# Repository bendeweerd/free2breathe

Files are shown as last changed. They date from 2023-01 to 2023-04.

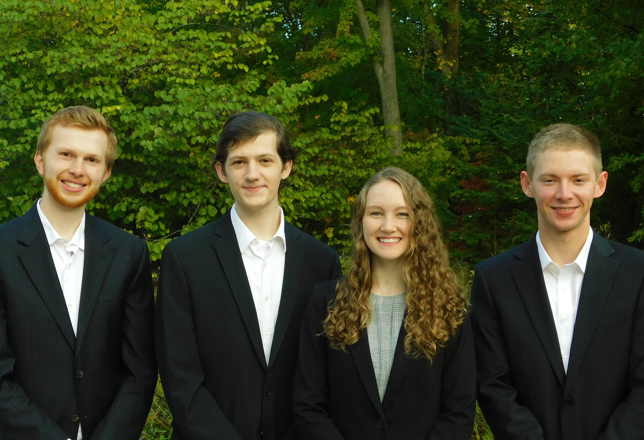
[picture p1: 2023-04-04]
website_resources/team.jpg

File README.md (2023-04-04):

# free<sub>2</sub>breathe
Calvin University Senior Design Team 17, 2022-2023.

Free<sub>2</sub>breathe is a hazardous gas detector built using [SPEC sensors](https://www.spec-sensors.com/) and a custom PCB. It detects short-term and long-term hazardous levels of
1. Carbon Monoxide
2. Ozone
3. Sulfur Dioxide
4. Nitrogen Dioxide

and alerts the user if any of these gases are present in concentrations that will cause long-term or short-term harm.

Visit our [webpage](https://bendeweerd.github.io/free2breathe/index.html) to download the instructional pamphlet.

Team Members: 
1. Nate Anderson
2. Jordan Alexander
3. Ben DeWeerd
4. Anna Giboney

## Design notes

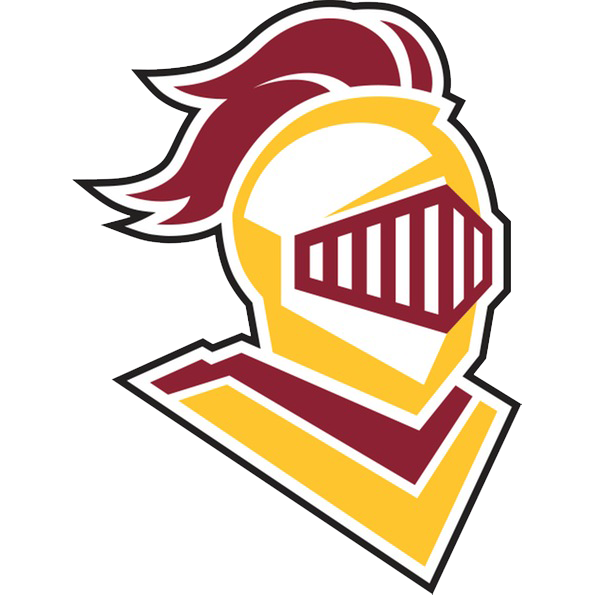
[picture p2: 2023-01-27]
free2breathe_pcb/knights.bmp

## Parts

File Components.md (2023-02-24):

# Components:

1. 1x Micro - Arduino Nano (Ben has)
2. 1x [ip5328](https://www.digipart.com/part/IP5328P)
3. 1x [Buzzer](https://www.digikey.com/en/products/detail/pui-audio-inc/AT-1127-ST-2-R/5011397)
4. 4x [MCP6044 Opamp](https://www.digikey.com/en/products/detail/microchip-technology/MCP6044-E-P/1098540)
5. 1x [Inductor](https://www.digikey.com/en/products/detail/abracon-llc/AMPLA5030S-2R2MT/12168435)
6. 1x [Thermistor](https://www.digikey.com/en/products/detail/mitsubishi-materials-u-s-a-corporation/TH20-3S104FT/12144110)
7. 1x [USB-C Connector](https://www.digikey.com/en/products/detail/gct/USB4110-GF-A/10384547)
8. 1x [Switch](https://www.digikey.com/en/products/detail/e-switch/EG1213/101735)
9. 1x [JST connector for LEDs](https://www.digikey.com/en/products/detail/jst-sales-america-inc/S3B-PH-K-S-LF-SN/926627)
10. 4x [Status LEDs](https://www.digikey.com/en/products/detail/inolux/INL-3AB30/7604618)
11. 4x [Charge LEDs (unless changed)](https://www.digikey.com/en/products/detail/qt-brightek-qtb/QBLP601-IW/4814655)
12. 1x [Q2 Transistor](https://www.digikey.com/en/products/detail/diodes-incorporated/DMN3404L-7/2052774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)
13. 1x [Q1 Transistor](https://www.digikey.com/en/products/detail/alpha-omega-semiconductor-inc/AO3401A/1855773)
14. 1x [10mOhm Resistor](https://www.digikey.com/en/products/detail/koa-speer-electronics-inc/UR73D2ATTD10L0F/9845679)

## REV 2:
1. 2x [15 Position headers for Nano](https://www.digikey.com/en/products/detail/sullins-connector-solutions/PPTC151LFBN-RC/810153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)
2. 12x [2 position headers for SPEC sensors](https://www.digikey.com/en/products/detail/adam-tech/2RS1-02-G/9833032)
3. 20x [Football Capacitors](https://www.digikey.com/en/products/detail/rubycon/50YXJ100MT78X11-5/3134938)
4. 1x [Thermistor](https://www.digikey.com/en/products/detail/mitsubishi-materials-u-s-a-corporation/TH20-3S104FT/12144110)

## To Purchase:
1. 4x [15 Position headers for Nano](https://www.digikey.com/en/products/detail/sullins-connector-solutions/PPTC151LFBN-RC/810153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)
2. 12x [2 position headers for SPEC sensors](https://www.digikey.com/en/products/detail/adam-tech/2RS1-02-G/9833032)
3. 30x [100nF 25V Capactiors](https://www.digikey.com/en/products/detail/samsung-electro-mechanics/CL10B104KA8NNNC/3886664)
4. 10x [1uF 25V Capacitors](https://www.digikey.com/en/products/detail/samsung-electro-mechanics/CL10A105KA8NNNC/3886760)
5. 2x [USB-C Connectors](https://www.digikey.com/en/products/detail/gct/USB4110-GF-A/10384547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)
6. 2x [2 kOhm Resistors](https://www.digikey.com/en/products/detail/susumu/RR0816P-202-D/432192)
7. 30x [1 MOhm Resistors](https://www.digikey.com/en/products/detail/yageo/RC0603JR-071ML/726678)
8. 4x [16.2 kOhm Resistors](https://www.digikey.com/en/products/detail/yageo/RC0603FR-0716K2L/726967)
9. 20x [100 kOhm Resistors](https://www.digikey.com/en/products/detail/yageo/RC0603FR-07100KL/726889)
10. 10x [49.9 Ohm Resistors](https://www.digikey.com/en/products/detail/yageo/RC0603FR-1349R9L/13694149)
11. 4x [499 kOhm Resistors](https://www.digikey.com/en/products/detail/yageo/RC0603FR-07499KL/727267)
12. 2x [143 kOhm Resistors](https://www.digikey.com/en/products/detail/yageo/RC0603FR-07143KL/726949)
13. 2x [Switch](https://www.digikey.com/en/products/detail/e-switch/EG1213/101735)
14. 2x [Thermistor](https://www.digikey.com/en/products/detail/mitsubishi-materials-u-s-a-corporation/TH20-3S104FT/12144110)

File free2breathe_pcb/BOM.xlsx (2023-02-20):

Source: | /home/bendeweerd/Documents/senior_design/free2breathe/free2breathe_pcb/free2breathe_pcb.kicad_sch
Date: | Thu 26 Jan 2023 10:10:45 AM EST
Tool: | Eeschema 6.0.9-8da3e8f707~116~ubuntu20.04.1
Generator: | /usr/share/kicad/plugins/bom_csv_grouped_by_value_with_fp.py
Component Count: | 101
Ref | Qnty | Value | Purchase Location | Link | Cmp name | Footprint | Description | Vendor
A1, | 1 | Arduino_Nano_v3.x | N/A |  | Arduino_Nano_v3.x | Module:Arduino_Nano | Arduino Nano v3.x
BT1, BT2, BT3, | 3 | Battery_Cell | N/A |  | Battery_Cell | switch:switch_pad | Single-cell battery
C1, C11, C13, | 3 | 10uF 25V | DigiKey | https://www.digikey.com/en/products/detail/samsung-electro-mechanics/CL10A106MA8NRNC/3887527 | C | Capacitor_SMD:C_0603_1608Metric | Unpolarized capacitor
C2, C7, C8, C9, C10, | 5 | 22uF 25V | DigiKey | https://www.digikey.com/en/products/detail/samsung-electro-mechanics/CL21A226MAYNNNE/10479857 | C | 0805 | Unpolarized capacitor
C3, C6, C12, | 3 | 100nF 25V | DigiKey | https://www.digikey.com/en/products/detail/samsung-electro-mechanics/CL10B104KA8NNNC/3886664 | C | Capacitor_SMD:C_0603_1608Metric | Unpolarized capacitor
C4, C5, | 2 | 2.2uF 16V | DigiKey | https://www.digikey.com/en/products/detail/samsung-electro-mechanics/CL10A225KO8NNNC/3886698 | C | Capacitor_SMD:C_0603_1608Metric | Unpolarized capacitor
C14, C16, C17, | 3 | 22uF 16V | DigiKey | https://www.digikey.com/en/products/detail/samsung-electro-mechanics/CL10A226MO7JZNC/7320581 | C | Capacitor_SMD:C_0603_1608Metric | Unpolarized capacitor
C15, | 1 | 22uF 16v |  |  | C | Capacitor_SMD:C_0603_1608Metric | Unpolarized capacitor
C18, C19, C20, C21, C22, C23, C24, C25, C26, C27, C28, C29, C30, C31, C32, | 15 | 0.1u | DigiKey | https://www.digikey.com/en/products/detail/samsung-electro-mechanics/CL10B104KO8NNNC/3886663 | C | Capacitor_SMD:C_0603_1608Metric | Unpolarized capacitor
D1, | 1 | Status_LED_1 | DigiKey | https://www.digikey.com/en/products/detail/inolux/INL-3AB30/7604618 | LED | LED_THT:LED_D3.0mm | Light emitting diode
D2, | 1 | Status_LED_2 |  |  | LED | LED_THT:LED_D3.0mm | Light emitting diode
D3, | 1 | Status_LED_3 |  |  | LED | LED_THT:LED_D3.0mm | Light emitting diode
D4, | 1 | Status_LED_4 |  |  | LED | LED_THT:LED_D3.0mm | Light emitting diode
D5, D6, D7, D8, | 4 | LED | DigiKey | https://www.digikey.com/en/products/detail/qt-brightek-qtb/QBLP601-IW/4814655 | LED | LED_SMD:LED_0603_1608Metric | Light emitting diode
H1, H2, H3, H4, H5, | 5 | MountingHole_Pad | N/A |  | MountingHole_Pad | MountingHole:MountingHole_3.2mm_M3_Pad_Via | Mounting Hole with connection
J1, | 1 | USB4110-GF-A_REVB | DigiKey | https://www.digikey.com/en/products/detail/gct/USB4110-GF-A/10384547 | USB4110-GF-A_REVB | components:GCT_USB4110-GF-A_REVB
J2, | 1 | LED_Connector | DigiKey | https://www.digikey.com/en/products/detail/jst-sales-america-inc/S3B-PH-K-S-LF-SN/926627 | Conn_01x03_Female | Connector_JST:JST_PH_S3B-PH-K_1x03_P2.00mm_Horizontal | Generic connector, single row, 01x03, script generated (kicad-library-utils/schlib/autogen/connector/)
J3, | 1 | Alarm_Connector | N/A |  | Conn_01x02_Female | alarm:AT_1127_ST_2_R_Alarm | Generic connector, single row, 01x02, script generated (kicad-library-utils/schlib/autogen/connector/)
L1, | 1 | 2.2uH | DigiKey | https://www.digikey.com/en/products/detail/abracon-llc/AMPLA5030S-2R2MT/12168435 | L | components:IND_AMPLA5030S2R2MT | Inductor
Q1, | 1 | AO3401A | DigiKey | https://www.digikey.com/en/products/detail/alpha-omega-semiconductor-inc/AO3401A/1855773 | AO3401A | Package_TO_SOT_SMD:SOT-23 | -4.0A Id, -30V Vds, P-Channel MOSFET, SOT-23
Q2, | 1 | DMN3404L | DigiKey | https://www.digikey.com/en/products/detail/diodes-incorporated/DMN3404L-7/2052774 | DMN3404L | Package_TO_SOT_SMD:SOT-23 | 5.8A Id, 30V Vds, N-Channel MOSFET, SOT-23
R1, R13, R23, | 3 | 10k | DigiKey | https://www.digikey.com/en/products/detail/rohm-semiconductor/ESR03EZPF1002/1983429 | R | Resistor_SMD:R_0603_1608Metric | Resistor
R2, | 1 | 10m | DigiKey | https://www.digikey.com/en/products/detail/koa-speer-electronics-inc/UR73D2ATTD10L0F/9845679 | R | Resistor_SMD:R_0805_2012Metric | Resistor
R3, | 1 | 100k 0.1% | DigiKey | https://www.digikey.com/en/products/detail/panasonic-electronic-components/ERJ-PB3B1003V/6212983 | R | Resistor_SMD:R_0603_1608Metric | Resistor
 |  | 14k 0.1% | DigiKey | https://www.digikey.com/en/products/detail/panasonic-electronic-components/ERJ-PB3B1402V/6212884
R4, R5, R6, R8, | 4 | R | DigiKey (got 220 ohm) | https://www.digikey.com/en/products/detail/yageo/RC0603FR-13220RL/14008234 | R | Resistor_SMD:R_0603_1608Metric | Resistor
R7, R9, | 2 | 100 | DigiKey | https://www.digikey.com/en/products/detail/rohm-semiconductor/SDR03EZPJ101/9674981 | R | Resistor_SMD:R_0603_1608Metric | Resistor
R10, | 1 | NC | N/A |  | R | Resistor_SMD:R_0603_1608Metric | Resistor
R11, | 1 | 82k 1% | DigiKey | https://www.digikey.com/en/products/detail/yageo/RC0603FR-1082KL/14286523 | R | Resistor_SMD:R_0603_1608Metric | Resistor
R12, R14, R15, R16, R18, R19, R20, R21, R22, R26, R27, R28, R29, R30, R31, R32, R33, R34, R35, | 19 | 10 | DigiKey | https://www.digikey.com/en/products/detail/rohm-semiconductor/ESR03EZPJ100/1983451 | R | Resistor_SMD:R_0603_1608Metric | Resistor
R17, R25, | 2 | 4.7k | DigiKey | https://www.digikey.com/en/products/detail/yageo/RC0603JR-074K7L/726785 | R | Resistor_SMD:R_0603_1608Metric | Resistor
R24, | 1 | 910 | DigiKey | https://www.digikey.com/en/products/detail/yageo/RC0603FR-07910RL/727429 | R | Resistor_SMD:R_0603_1608Metric | Resistor
S1, | 1 | EG1213 | DigiKey | https://www.digikey.com/en/products/detail/e-switch/EG1213/101735 | EG1213 | components:SW_EG1213
TH1, | 1 | 100k@25c | DigiKey | https://www.digikey.com/en/products/detail/mitsubishi-materials-u-s-a-corporation/TH20-3S104FT/12144110 | Thermistor | Resistor_SMD:R_0805_2012Metric | Temperature dependent resistor
U1, | 1 | IP5328 | N/A |  | IP5328 | Package_DFN_QFN:QFN-40-1EP_6x6mm_P0.5mm_EP4.6x4.6mm
U2, U3, U6, U8, | 4 | MCP6044-E/P | N/A |  | MCP6044-E{slash}P | components:DIP254P762X533-14
U4, | 1 | SO2 Sensor | N/A |  | 110-102 | components:XDCR_110-102
U5, | 1 | CO Sensor | N/A |  | 110-102 | components:XDCR_110-102
U7, | 1 | O3 Sensor | N/A |  | 110-102 | components:XDCR_110-102
U9, | 1 | NO2 Sensor | N/A |  | 110-102 | components:XDCR_110-102

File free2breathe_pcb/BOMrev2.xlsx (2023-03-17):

Source: | C:\Users\legen\OneDrive\Documents\SeniorDesign\free2breathe\free2breathe_pcb\free2breathe_pcb.kicad_sch
Date: | 2023-02-20 15:13
Tool: | Eeschema (6.0.9)
Generator: | C:\Program Files\KiCad\6.0\bin\scripting\plugins/bom_csv_grouped_by_value_with_fp.py
Component Count: | 111
Ref | Qnty to Order | Qnty | Value | Cmp name | Footprint | Description
A1, |  | 1 | Arduino_Nano_v3.x | Arduino_Nano_v3.x | Module:Arduino_Nano | Arduino Nano v3.x
BT1, BT2, BT3, |  | 3 | Battery_Cell | Battery_Cell | switch:switch_pad | Single-cell battery
C1, C11, C13, |  | 3 | 10uF 25V | C | Capacitor_SMD:C_0603_1608Metric | Unpolarized capacitor
C2, C7, C8, C9, C10, |  | 5 | 22uF 25V | C | Capacitor_SMD:C_0805_2012Metric | Unpolarized capacitor
C3, C6, C12, | 6 | 3 | 100nF 25V | C | Capacitor_SMD:C_0603_1608Metric | Unpolarized capacitor
C4, C5, |  | 2 | 2.2uF 16V | C | Capacitor_SMD:C_0603_1608Metric | Unpolarized capacitor
C14, C15, C16, C17, |  | 4 | 22uF 16V | C | Capacitor_SMD:C_0603_1608Metric | Unpolarized capacitor
C18, C19, C24, C25, | 8 | 4 | 1u | C | Capacitor_SMD:C_0603_1608Metric | Unpolarized capacitor
C20, C21, C22, C23, C26, C27, C28, C29, C30, C31, C32, C33, | 20 | 12 | 0.1u | C | Capacitor_SMD:C_0603_1608Metric | Unpolarized capacitor
D1, |  | 1 | Status_LED_1 | LED | LED_THT:LED_D3.0mm | Light emitting diode
D2, |  | 1 | Status_LED_2 | LED | LED_THT:LED_D3.0mm | Light emitting diode
D3, |  | 1 | Status_LED_3 | LED | LED_THT:LED_D3.0mm | Light emitting diode
D4, |  | 1 | Status_LED_4 | LED | LED_THT:LED_D3.0mm | Light emitting diode
D5, D6, D7, D8, |  | 4 | LED | LED | LED_SMD:LED_0603_1608Metric | Light emitting diode
H1, H2, H3, H4, H5, |  | 5 | MountingHole_Pad | MountingHole_Pad | MountingHole:MountingHole_3.2mm_M3_Pad_Via | Mounting Hole with connection
J1, | 2 | 1 | USB4110-GF-A_REVB | USB4110-GF-A_REVB | components:GCT_USB4110-GF-A_REVB
J2, |  | 1 | LED_Connector | Conn_01x03_Female | Connector_JST:JST_PH_S3B-PH-K_1x03_P2.00mm_Horizontal | Generic connector, single row, 01x03, script generated (kicad-library-utils/schlib/autogen/connector/)
J3, |  | 1 | Alarm_Connector | Conn_01x02_Female | alarm:AT_1127_ST_2_R_Alarm | Generic connector, single row, 01x02, script generated (kicad-library-utils/schlib/autogen/connector/)
J4, |  | 1 | Conn_01x02_Female | Conn_01x02_Female | switch:switch_pad | Generic connector, single row, 01x02, script generated (kicad-library-utils/schlib/autogen/connector/)
L1, |  | 1 | 2.2uH | L | components:IND_AMPLA5030S2R2MT | Inductor
Q1, |  | 1 | AO3401A | AO3401A | Package_TO_SOT_SMD:SOT-23 | -4.0A Id, -30V Vds, P-Channel MOSFET, SOT-23
Q2, |  | 1 | DMN3404L | DMN3404L | Package_TO_SOT_SMD:SOT-23 | 5.8A Id, 30V Vds, N-Channel MOSFET, SOT-23
R1, |  | 1 | 10k | R | Resistor_SMD:R_0603_1608Metric | Resistor
R2, |  | 1 | 10m | R | Resistor_SMD:R_0805_2012Metric | Resistor
R3, |  | 1 | 100k 0.1% | R | Resistor_SMD:R_0603_1608Metric | Resistor
R4, R5, R6, R8, |  | 4 | 220 | R | Resistor_SMD:R_0603_1608Metric | Resistor
R7, R9, |  | 2 | 100 | R | Resistor_SMD:R_0603_1608Metric | Resistor
R10, |  | 1 | NC | R | Resistor_SMD:R_0603_1608Metric | Resistor
R11, |  | 1 | 82k 1% | R | Resistor_SMD:R_0603_1608Metric | Resistor
R12, | 2 | 1 | 2k | R | Resistor_SMD:R_0603_1608Metric | Resistor
R13, R14, R16, R17, R20, R21, R26, R28, R29, R31, R34, R35, | 24 | 12 | 1M | R | Resistor_SMD:R_0603_1608Metric | Resistor
R15, R30, | 4 | 2 | 16.2k | R | Resistor_SMD:R_0603_1608Metric | Resistor
R18, R19, R32, R33, R24, R39, R42, | 14 | 7 | 100K | R | Resistor_SMD:R_0603_1608Metric | Resistor
R22, R23, R37, R38, | 8 | 4 | 49.9 | R | Resistor_SMD:R_0603_1608Metric | Resistor
R25, R40, | 4 | 2 | 499k | R | Resistor_SMD:R_0603_1608Metric | Resistor
R27, | 2 | 1 | 143k | R | Resistor_SMD:R_0603_1608Metric | Resistor
R36, |  | 1 | 14k 0.1% | R | Resistor_SMD:R_0603_1608Metric | Resistor
R41, |  | 1 | 10 | R | Resistor_SMD:R_0603_1608Metric | Resistor
S1, | 2 | 1 | EG1213 | EG1213 | components:SW_EG1213
TH1, TH2, | 2 | 2 | 100k@25c | Thermistor | Resistor_SMD:R_0805_2012Metric | Temperature dependent resistor
U1, |  | 1 | IP5328 | IP5328 | Package_DFN_QFN:QFN-40-1EP_6x6mm_P0.5mm_EP4.6x4.6mm
U2, U3, U6, U7, |  | 4 | MCP6044-E/P | MCP6044-E/P | components:DIP254P762X533-14
U4, |  | 1 | O3 Sensor | 110-102 | components:XDCR_110-102
U5, |  | 1 | CO Sensor | 110-102 | components:XDCR_110-102
U8, |  | 1 | SO2 Sensor | 110-102 | components:XDCR_110-102
U9, |  | 1 | NO2 Sensor | 110-102 | components:XDCR_110-102

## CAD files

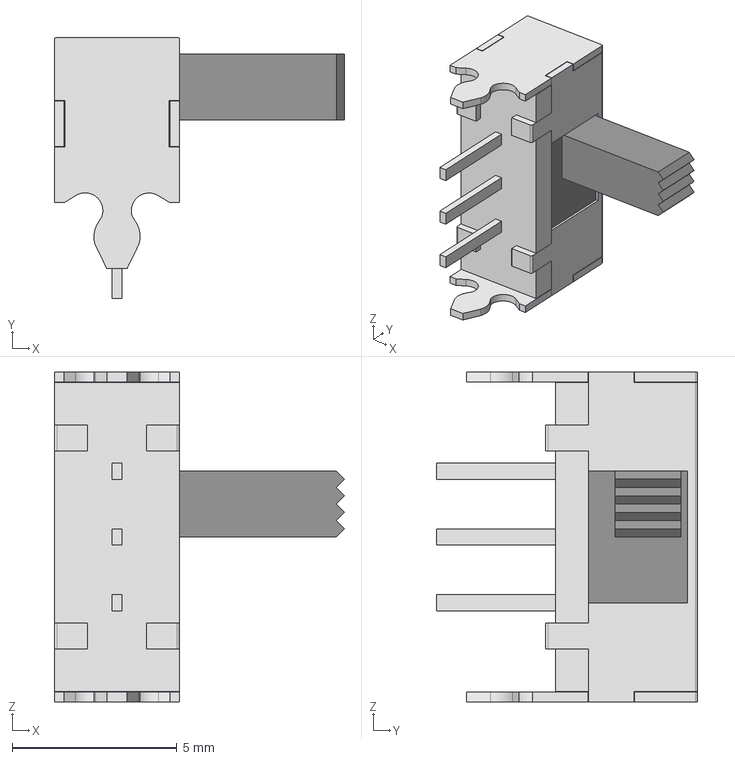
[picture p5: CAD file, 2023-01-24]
free2breathe_pcb/components/EG1213.step
8.80 x 7.90 x 10.00 mm

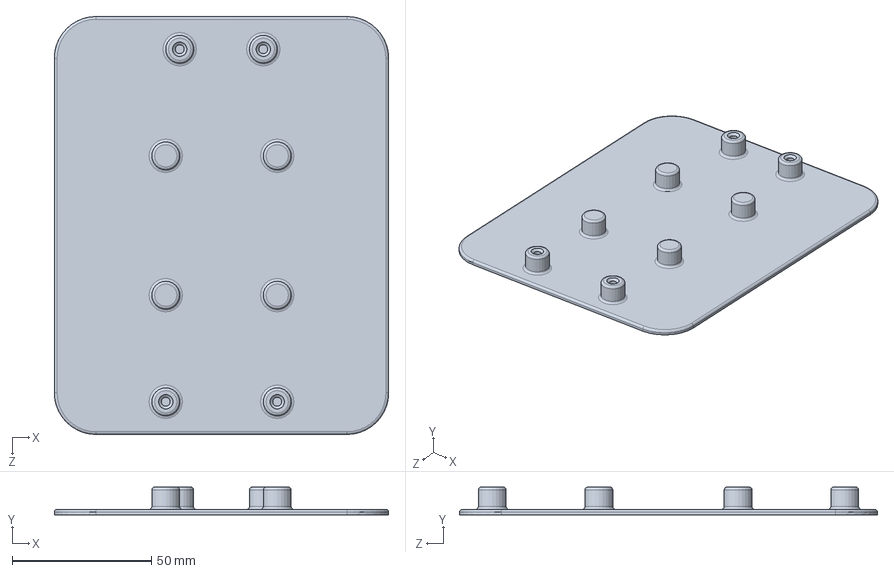
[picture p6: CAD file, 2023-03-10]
free2breathe_pcb/stencil_jig.SLDPRT
120.0 x 10.0 x 150.0 mm

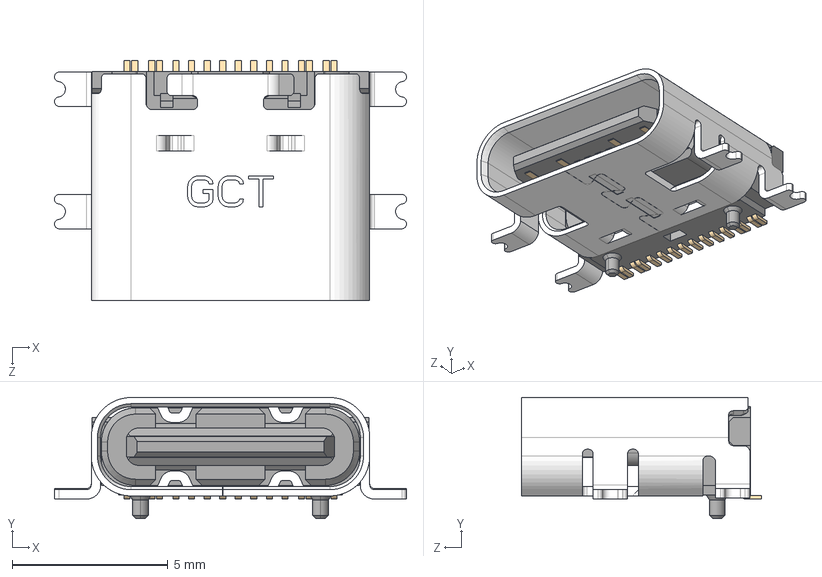
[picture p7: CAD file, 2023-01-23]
free2breathe_pcb/components/USB4110-GF-A_REVB.step
11.3 x 3.89 x 7.70 mm

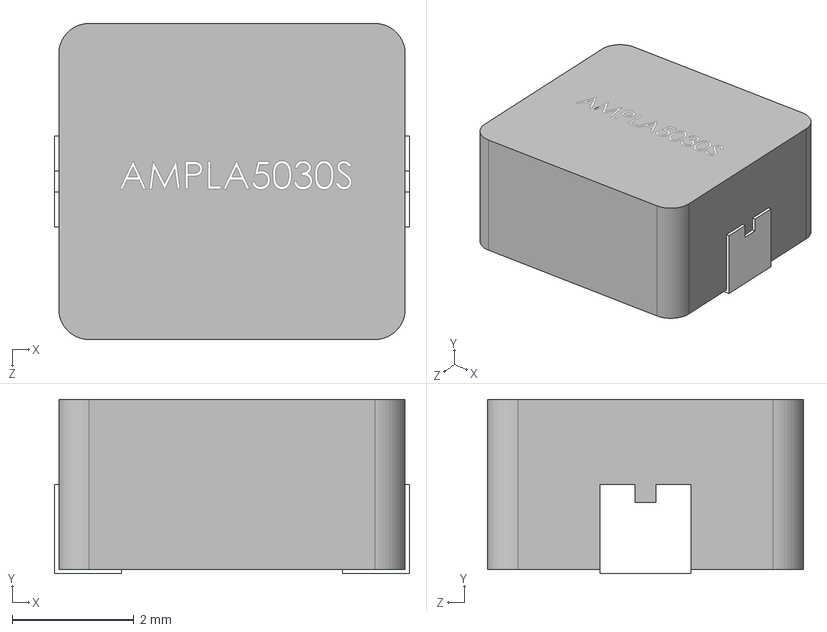
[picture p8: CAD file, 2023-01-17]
free2breathe_pcb/components/AMPLA5030S2R2MT.step
5.84 x 2.87 x 5.20 mm

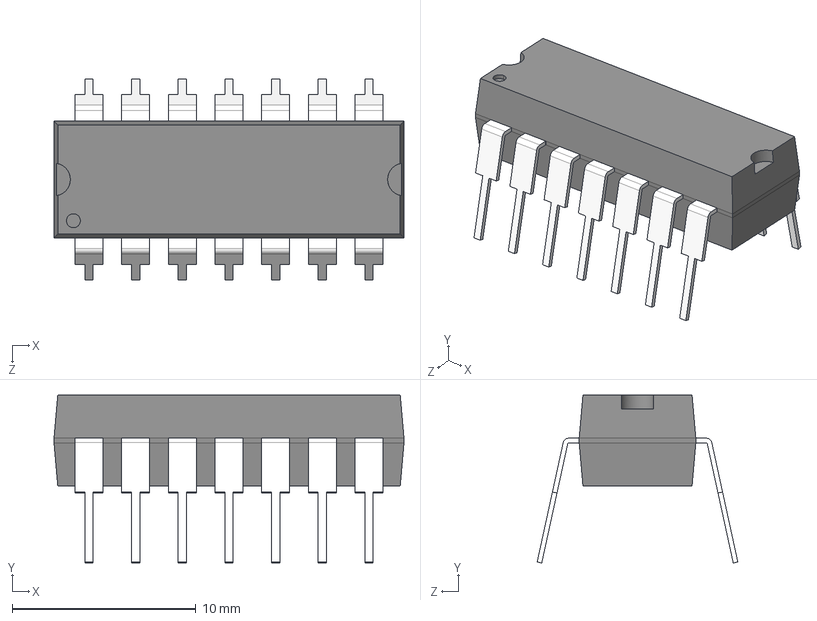
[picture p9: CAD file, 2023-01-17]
free2breathe_pcb/components/MCP6044-E_P.step
19.1 x 9.14 x 10.9 mm

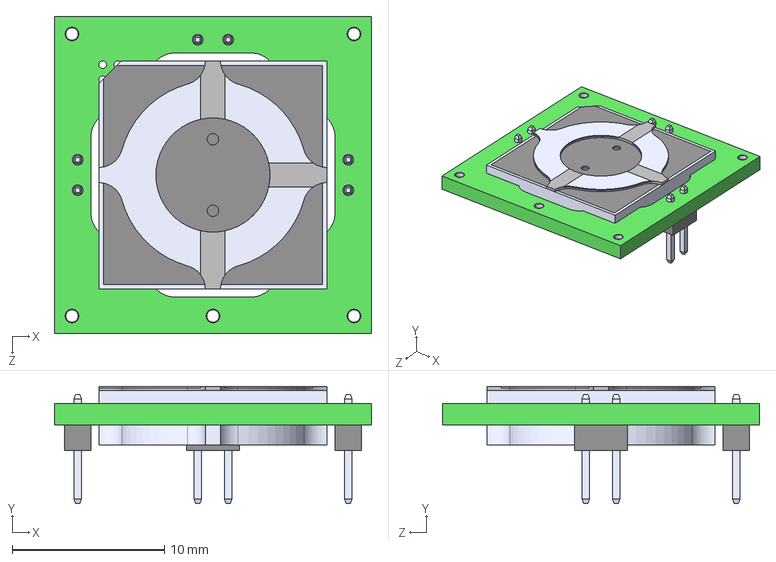
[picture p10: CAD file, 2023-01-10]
free2breathe_pcb/components/110-102.step
20.8 x 7.69 x 20.8 mm

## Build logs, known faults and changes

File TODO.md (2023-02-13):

### PCB TODO

1. <s>Determine USB-C connector, get 3d model and footprint</s>
2. <s>Create a footprint and 3D model for the SPEC sensors</s>
3. <s>Add LED connector</s>
4. <s>Determine supporting infrastructure for other SPEC sensors</s>
5. <s>Add SPEC sensors to schematic with infrastructure</s>
6. <s>Find [alarm](https://www.digikey.com/en/products/detail/pui-audio-inc/AT-1127-ST-2-R/5011397) and add to design</s>
7. <s>Add power switch</s>
8. <s>Add status LEDs</s>
9. <s>Finish sensor biasing</s>
10. <s>Determine how we want to measure and indicate battery charge state</s>
11. <s>Determine which LEDs we want, add footprints</s>
12. <s>Determine where to power the Arduino from</s>
13. <s>Determine battery footprint (same as switch pad?)</s>
14. <s>Find female connectors for Arduino</s>
15. <s>Source Transistors</s>
16. <s>Change Power status LEDs to small SMT</s>
17. <s>Add mounting holes (to ground)</s>
18. <s>Change LED connector from vertical JST (too high) to ?(solder pads)</s>
19. <s>Adjust LED placements for both status and power</s>
20. <s>Place buzzer and LED connector</s>
21. <s>Route traces</s>
22. <s>Adjust Via size for power traces?</s>
23. <s>Check guidelines on IC datasheet (especially for trace separation)</s>
24. <s>Current sense resistor</s>
25. <s>Determine whether unused pins should be high or low</s>
26. <s>Add stitching vias</s>
27. <s>Adjust silkscreen labels</s>
28. <s>Add filled zones</s>
29. <s>Generate BOM, order components</s>
30. <s>Generate Gerber files, order boards</s>

## REV 2
1. <s>Space LEDs further</s>
2. <s>Add standoffs for SPEC sensors (non-standard spacing)</s>
3. Order Arduino and sensor standoffs
4. <s>Verify schematic</s>
5. <s>Update board layout with new schematic</s>
6. Update BOM
7. Order new parts
8. Battery spot-welding
9. <s>Update schematic and layout with thermistor (on Analog Input)</s>
10. Give mechanicals updated .step file
11. <s>Ensure buzzer is on PWM pin</s> (9)
12. <s>Separate sensor grounds from others</s> (Separated LEDs and Buzzer instead)
13. <s>Add solder/test points for Arduino supply voltage</s>
14. Test Power System
15. <s>Add buzzer resistor</s>

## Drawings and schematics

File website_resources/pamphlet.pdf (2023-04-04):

# FREE2

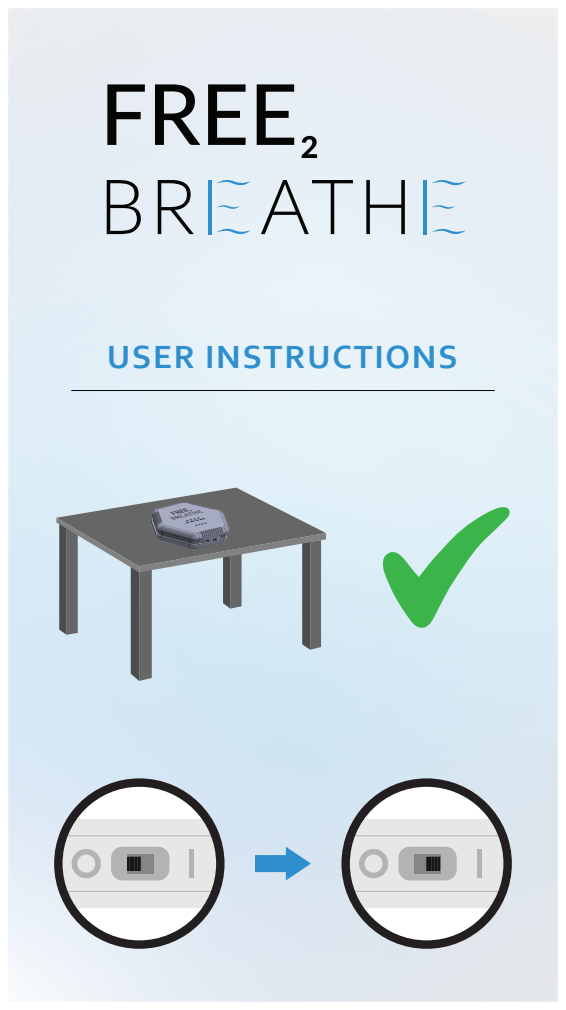
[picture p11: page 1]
USER INSTRUCTIONS

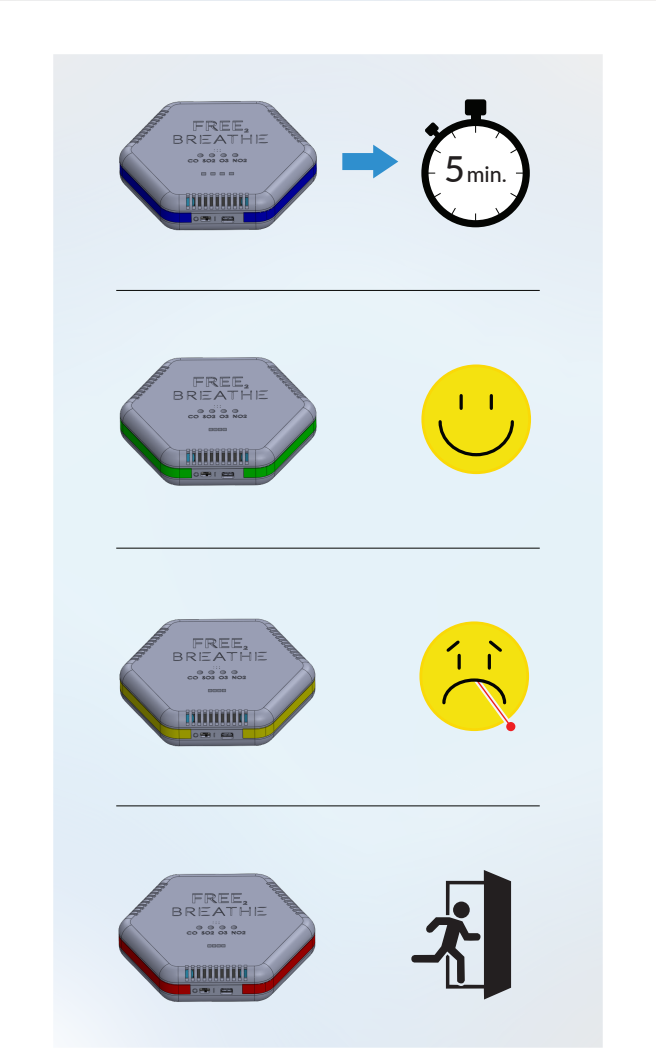
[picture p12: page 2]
5min.

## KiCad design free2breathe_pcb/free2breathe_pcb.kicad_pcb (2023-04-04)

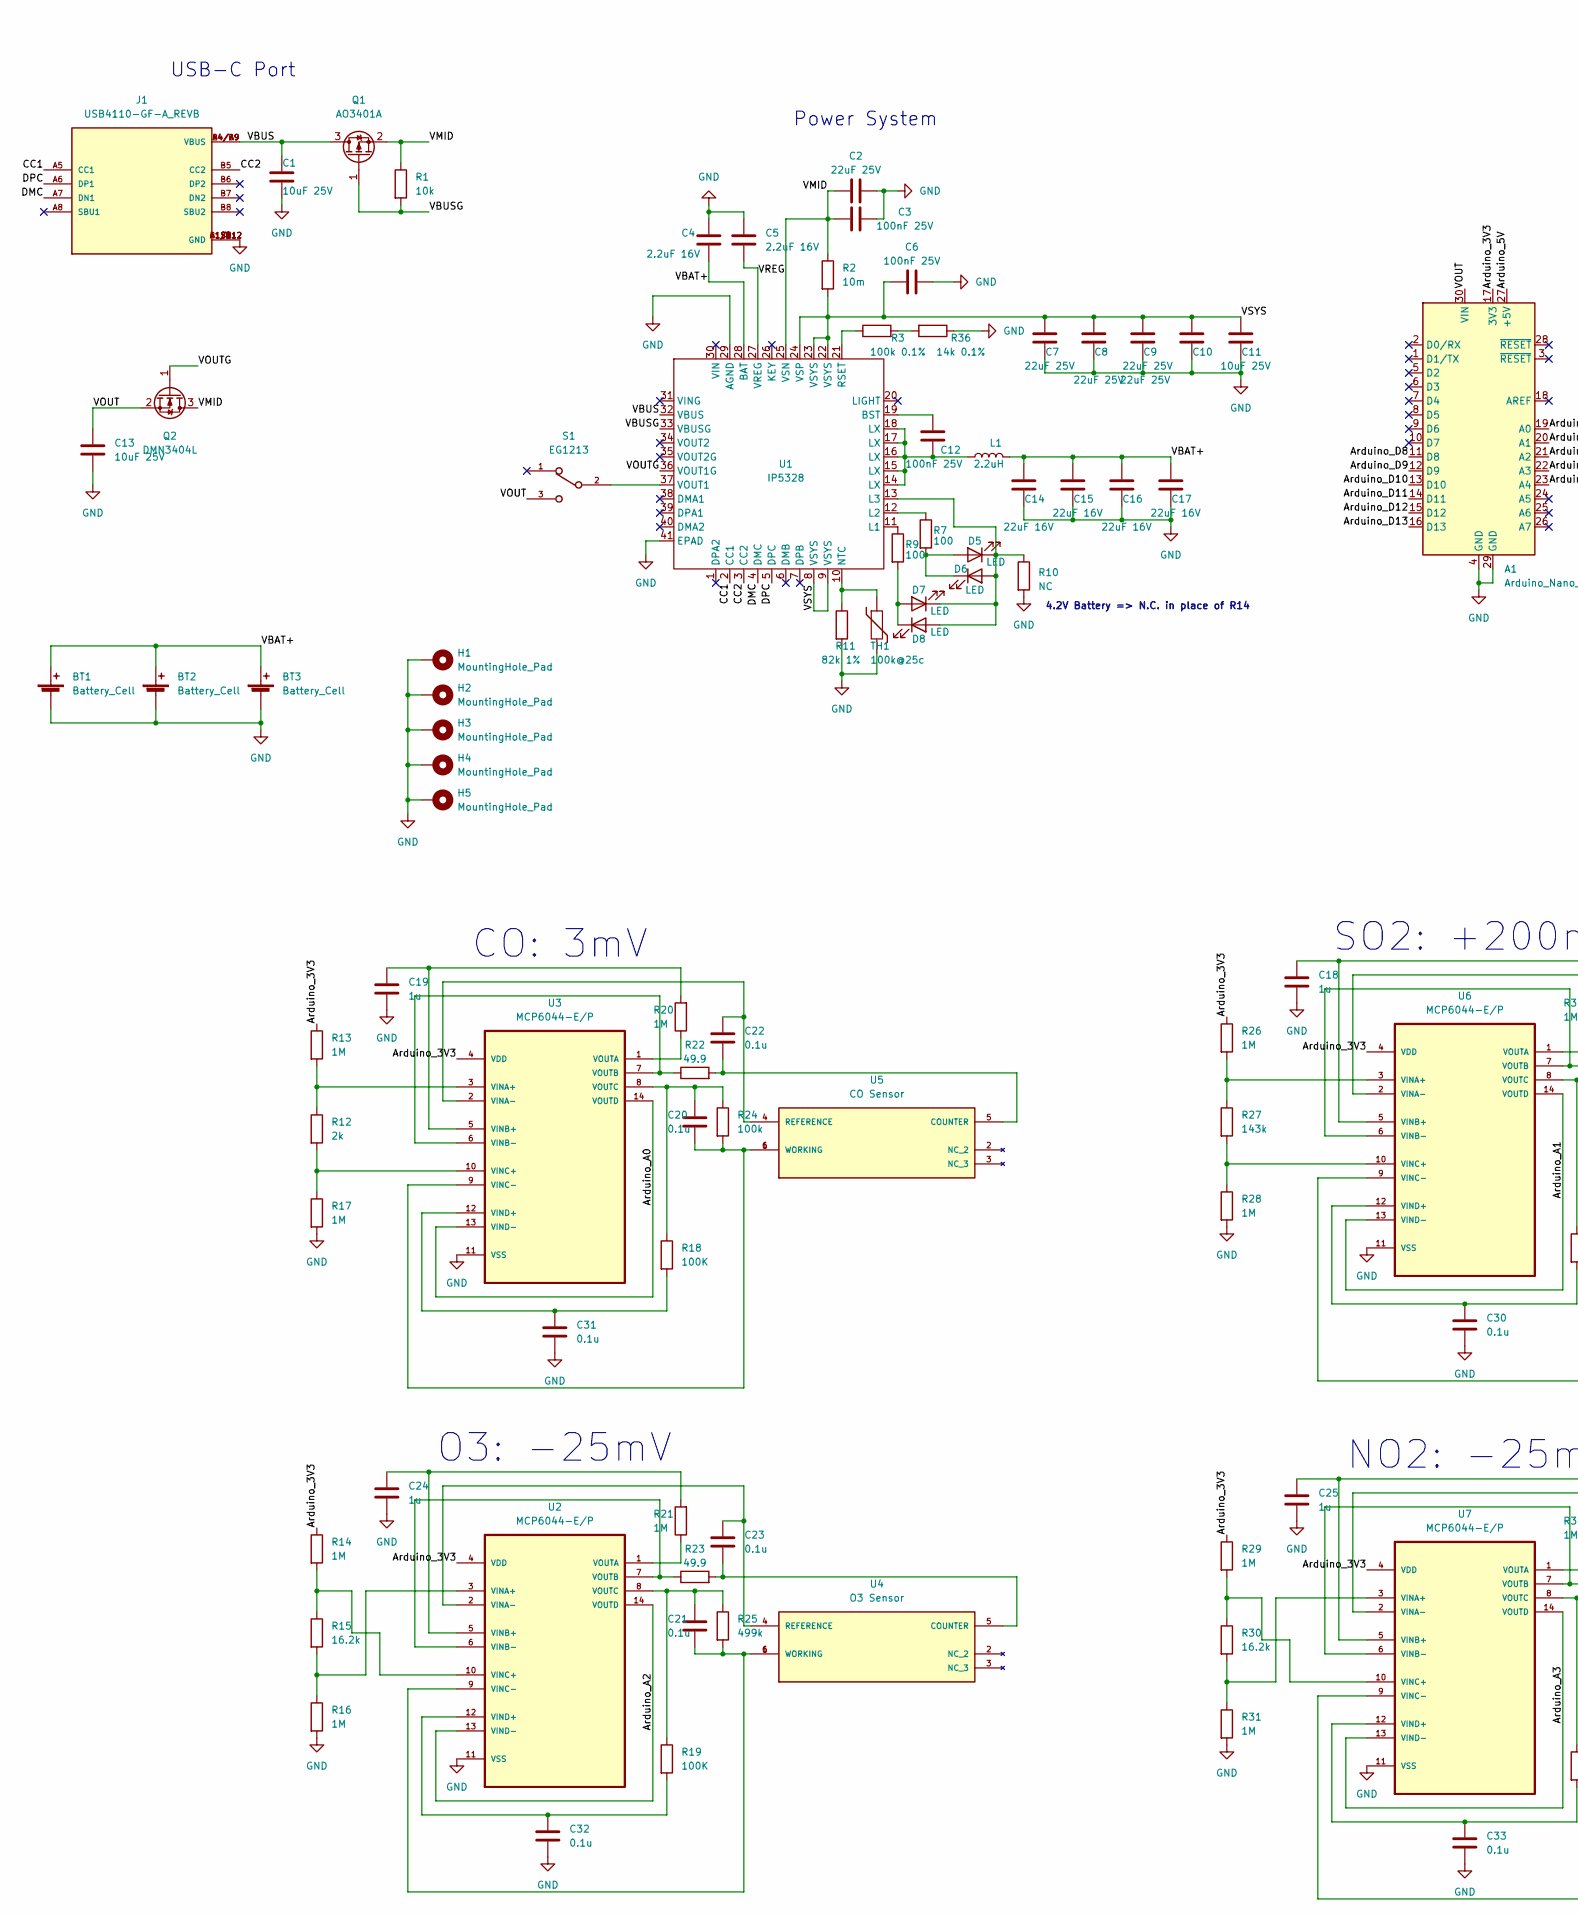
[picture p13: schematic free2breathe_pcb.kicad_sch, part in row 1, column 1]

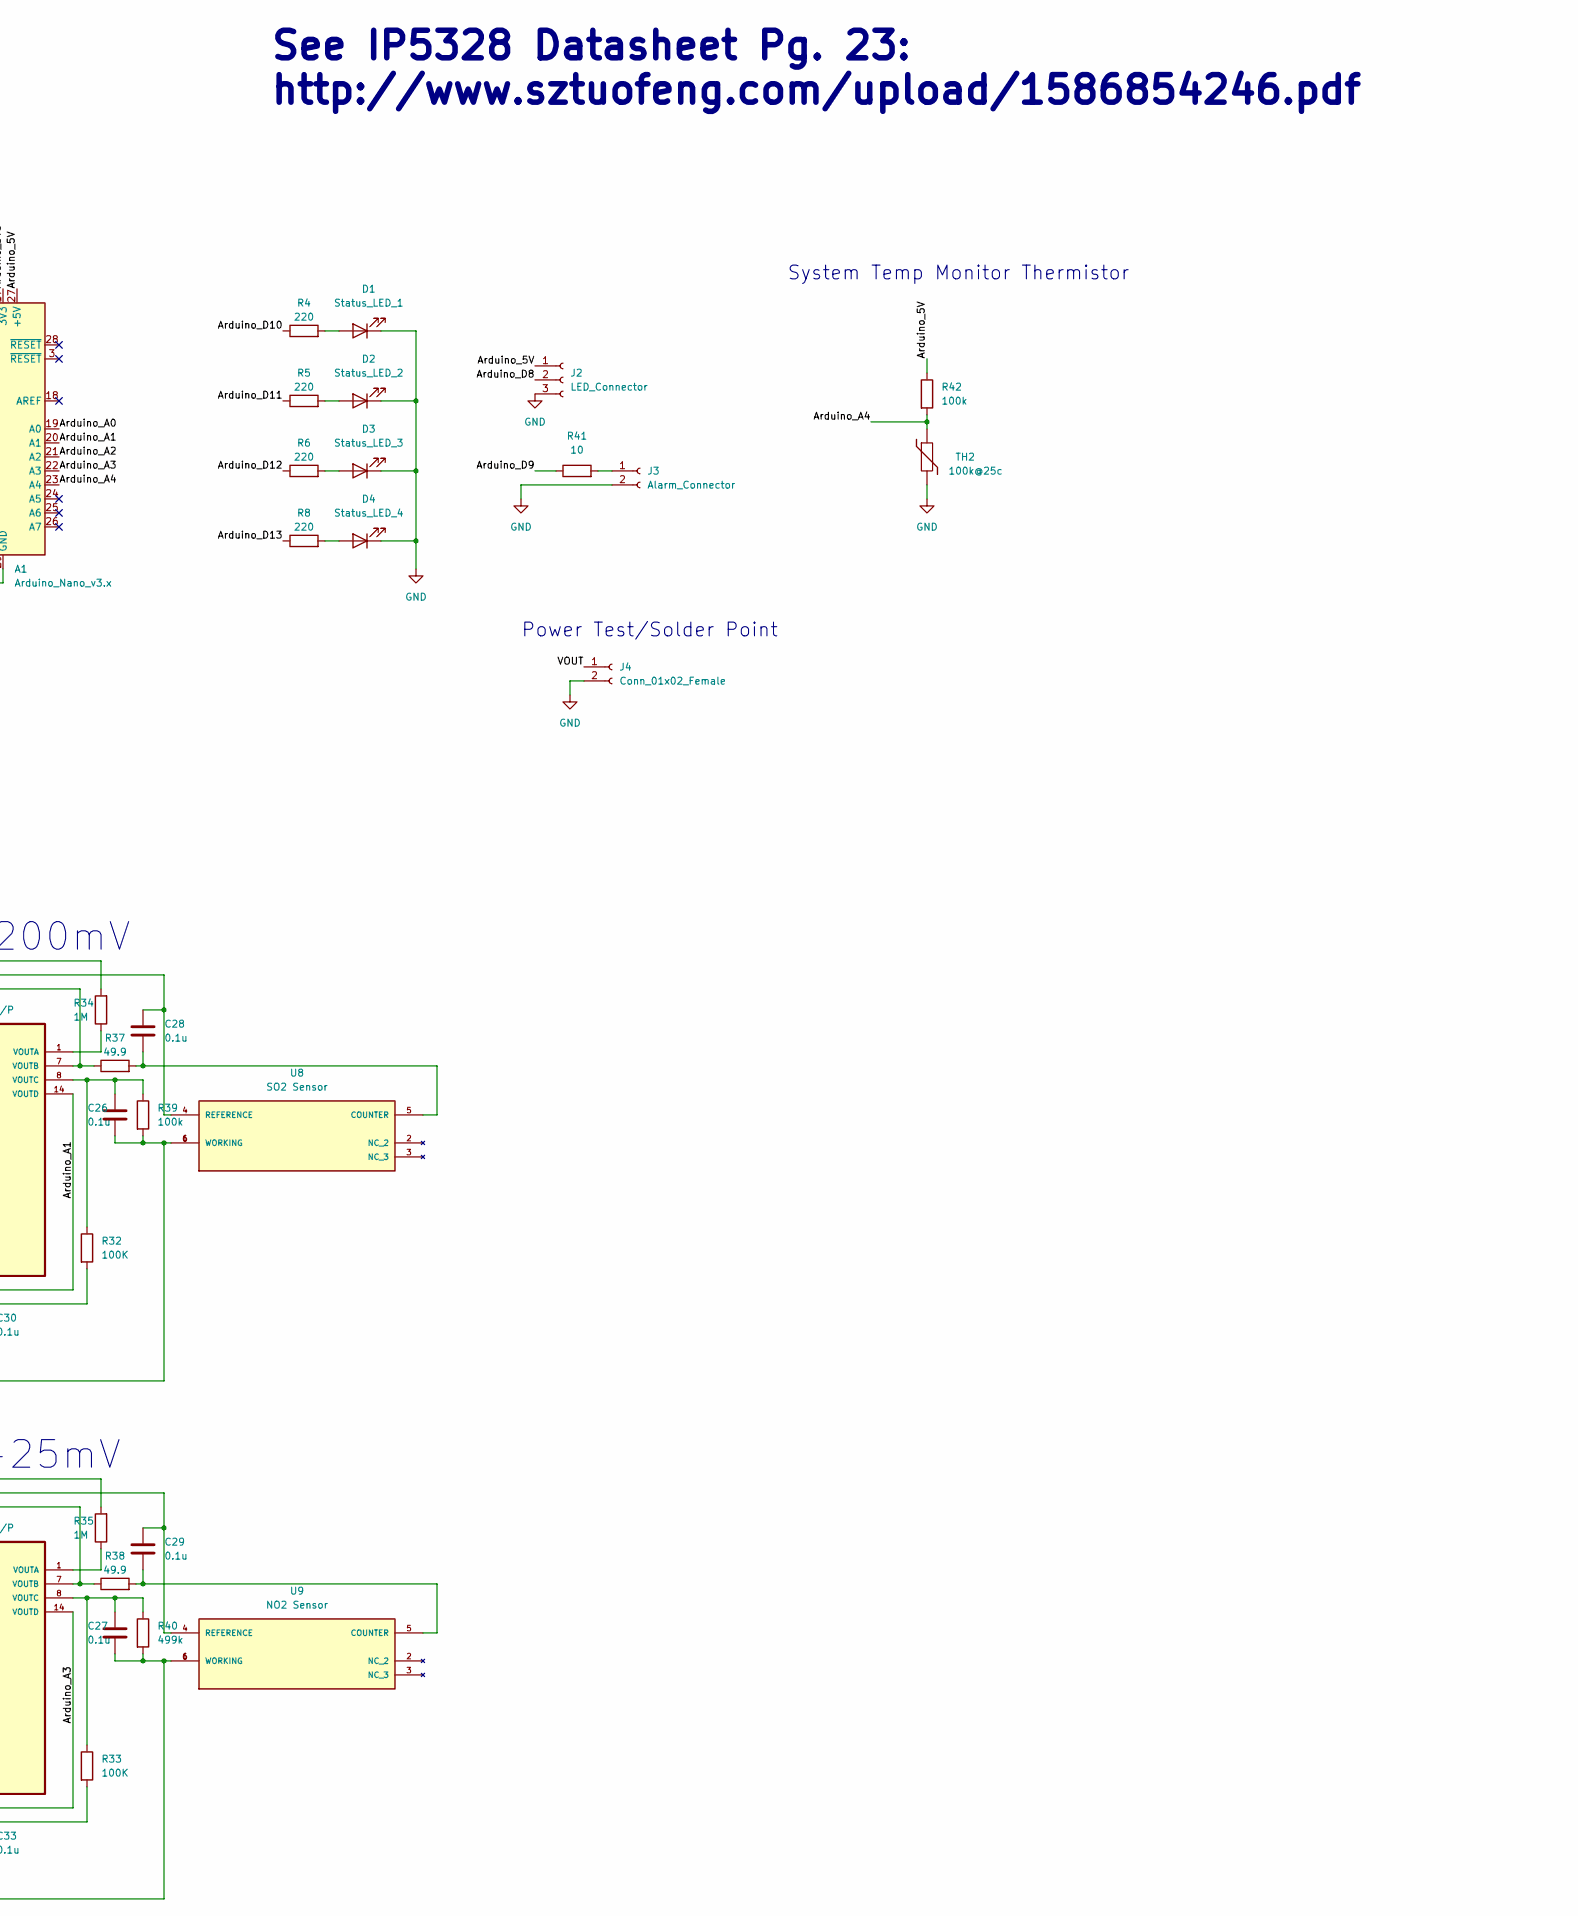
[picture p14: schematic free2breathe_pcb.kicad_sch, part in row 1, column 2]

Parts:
A1: Arduino_Nano_v3.x; Arduino_Nano
BT1, BT2, BT3: Battery_Cell; switch_pad
C1, C11, C13: 10uF 25V; C_0603_1608Metric
C2, C7, C8, C9, C10: 22uF 25V; C_0805_2012Metric
C3, C6, C12: 100nF 25V; C_0603_1608Metric
C4, C5: 2.2uF 16V; C_0603_1608Metric
C14, C15, C16, C17: 22uF 16V; C_0603_1608Metric
C18, C19, C24, C25: 1u; C_0603_1608Metric
C20, C21, C22, C23, C26, C27, C28, C29, C30, C31, C32, C33: 0.1u; C_0603_1608Metric
D1: Status_LED_1; LED_D3.0mm
D2: Status_LED_2; LED_D3.0mm
D3: Status_LED_3; LED_D3.0mm
D4: Status_LED_4; LED_D3.0mm
D5, D6, D7, D8: LED; LED_0603_1608Metric
H1, H2, H3, H4, H5: MountingHole_Pad; MountingHole_3.2mm_M3_Pad_Via
J1: USB4110-GF-A_REVB; GCT_USB4110-GF-A_REVB; PARTREV B
J2: LED_Connector; JST_PH_S3B-PH-K_1x03_P2.00mm_Horizontal
J3: Alarm_Connector; AT_1127_ST_2_R_Alarm
J4: Conn_01x02_Female; switch_pad
L1: 2.2uH; IND_AMPLA5030S2R2MT
Q1: AO3401A; SOT-23
Q2: DMN3404L; SOT-23
R1: 10k; R_0603_1608Metric
R2: 10m; R_0805_2012Metric
R3: 100k 0.1%; R_0603_1608Metric
R4, R5, R6, R8: 220; R_0603_1608Metric
R7, R9: 100; R_0603_1608Metric
R10: NC; R_0603_1608Metric
R11: 82k 1%; R_0603_1608Metric
R12: 2k; R_0603_1608Metric
R13, R14, R16, R17, R20, R21, R26, R28, R29, R31, R34, R35: 1M; R_0603_1608Metric
R15, R30: 16.2k; R_0603_1608Metric
R18, R19, R32, R33: 100K; R_0603_1608Metric
R22, R23, R37, R38: 49.9; R_0603_1608Metric
R24, R39, R42: 100k; R_0603_1608Metric
R25, R40: 499k; R_0603_1608Metric
R27: 143k; R_0603_1608Metric
R36: 14k 0.1%; R_0603_1608Metric
R41: 10; R_0603_1608Metric
S1: EG1213; SW_EG1213
TH1, TH2: 100k@25c; R_0805_2012Metric
U1: IP5328; QFN-40-1EP_6x6mm_P0.5mm_EP4.6x4.6mm
U2, U3, U6, U7: MCP6044-E/P; DIP254P762X533-14; MPN MCP6044-E/P
U4: O3 Sensor; XDCR_110-102; PARTREV April 2017
U5: CO Sensor; XDCR_110-102; PARTREV April 2017
U8: SO2 Sensor; XDCR_110-102; PARTREV April 2017
U9: NO2 Sensor; XDCR_110-102; PARTREV April 2017

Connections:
/Arduino_3V3: A1.17 (3V3), R13.1, R14.1, R26.1, R29.1, U2.4 (VDD), U3.4 (VDD), U6.4 (VDD), U7.4 (VDD)
/Arduino_5V: A1.27 (+5V), J2.1, R42.1
/Arduino_A0: A1.19 (A0), U3.13 (VIND-), U3.14 (VOUTD)
/Arduino_A1: A1.20 (A1), U6.13 (VIND-), U6.14 (VOUTD)
/Arduino_A2: A1.21 (A2), U2.13 (VIND-), U2.14 (VOUTD)
/Arduino_A3: A1.22 (A3), U7.13 (VIND-), U7.14 (VOUTD)
/Arduino_A4: A1.23 (A4), R42.2, TH2.1
/Arduino_D8: A1.11 (D8), J2.2
/Arduino_D9: A1.12 (D9), R41.1
/Arduino_D10: A1.13 (D10), R4.1
/Arduino_D11: A1.14 (D11), R5.1
/Arduino_D12: A1.15 (D12), R6.1
/Arduino_D13: A1.16 (D13), R8.1
/CC1: J1.A5 (CC1), U1.2 (CC1)
/CC2: J1.B5 (CC2), U1.3 (CC2)
/DMC: J1.A7 (DN1), U1.4 (DMC)
/DPC: J1.A6 (DP1), U1.5 (DPC)
/VBAT+: BT1.1 (+), BT2.1 (+), BT3.1 (+), C4.2, C14.1, C15.1, C16.1, C17.1, L1.2, U1.28 (BAT)
/VBUS: C1.1, J1.A4/B9 (VBUS), J1.B4/A9 (VBUS), Q1.3 (D), U1.32 (VBUS)
/VBUSG: Q1.1 (G), R1.2, U1.33 (VBUSG)
/VMID: C2.2, C3.2, Q1.2 (S), Q2.3 (D), R1.1, R2.1, U1.25 (VSN)
/VOUT: A1.30 (VIN), C13.1, J4.1, Q2.2 (S), S1.3
/VOUTG: Q2.1 (G), U1.36 (VOUT1G)
/VREG: C5.2, U1.27 (VREG)
/VSYS: C6.1, C7.1, C8.1, C9.1, C10.1, C11.1, R2.2, U1.8 (VSYS), U1.9 (VSYS), U1.22 (VSYS), U1.23 (VSYS), U1.24 (VSP)
GND: A1.4 (GND), A1.29 (GND), BT1.2 (-), BT2.2 (-), BT3.2 (-), C1.2, C2.1, C3.1, C4.1, C5.1, C6.2, C7.2, C8.2, C9.2, C10.2, C11.2, C13.2, C14.2, C15.2, C16.2, C17.2, C18.2, C19.2, C24.2, C25.2, C30.2, C31.2, C32.2, C33.2, D1.1 (K), D2.1 (K), D3.1 (K), D4.1 (K), H1.1, H2.1, H3.1, H4.1, H5.1, J1.A1/B12 (GND), J1.B1/A12 (GND), J1.S1 (GND), J1.S2 (GND), J1.S3 (GND), J1.S4 (GND), J2.3, J3.2, J4.2, R10.2, R11.2, R16.2, R17.2, R28.2, R31.2, R36.1, TH1.2, TH2.2, U1.29 (AGND), U1.41 (EPAD), U2.11 (VSS), U3.11 (VSS), U6.11 (VSS), U7.11 (VSS)
unnamed: C12.1, U1.19 (BST)
unnamed: C12.2, L1.1, U1.14 (LX), U1.15 (LX), U1.16 (LX), U1.17 (LX), U1.18 (LX)
unnamed: C18.1, R34.2, U6.5 (VINB+)
unnamed: C19.1, R20.2, U3.5 (VINB+)
unnamed: C20.1, R24.2, U3.9 (VINC-), U5.1 (WORKING), U5.6 (WORKING)
unnamed: C20.2, R18.1, R24.1, U3.8 (VOUTC)
unnamed: C21.1, R25.2, U2.9 (VINC-), U4.1 (WORKING), U4.6 (WORKING)
unnamed: C21.2, R19.1, R25.1, U2.8 (VOUTC)
unnamed: C22.1, U3.2 (VINA-), U5.4 (REFERENCE)
unnamed: C22.2, R22.2, U5.5 (COUNTER)
unnamed: C23.1, U2.2 (VINA-), U4.4 (REFERENCE)
unnamed: C23.2, R23.2, U4.5 (COUNTER)
unnamed: C24.1, R21.2, U2.5 (VINB+)
unnamed: C25.1, R35.2, U7.5 (VINB+)
unnamed: C26.1, R39.2, U6.9 (VINC-), U8.1 (WORKING), U8.6 (WORKING)
unnamed: C26.2, R32.1, R39.1, U6.8 (VOUTC)
unnamed: C27.1, R40.2, U7.9 (VINC-), U9.1 (WORKING), U9.6 (WORKING)
unnamed: C27.2, R33.1, R40.1, U7.8 (VOUTC)
unnamed: C28.1, U6.2 (VINA-), U8.4 (REFERENCE)
unnamed: C28.2, R37.2, U8.5 (COUNTER)
unnamed: C29.1, U7.2 (VINA-), U9.4 (REFERENCE)
unnamed: C29.2, R38.2, U9.5 (COUNTER)
unnamed: C30.1, R32.2, U6.12 (VIND+)
unnamed: C31.1, R18.2, U3.12 (VIND+)
unnamed: C32.1, R19.2, U2.12 (VIND+)
unnamed: C33.1, R33.2, U7.12 (VIND+)
unnamed: D1.2 (A), R4.2
unnamed: D2.2 (A), R5.2
unnamed: D3.2 (A), R6.2
unnamed: D4.2 (A), R8.2
unnamed: D5.1 (K), D6.2 (A), D7.1 (K), D8.2 (A), R10.1, U1.13 (L3)
unnamed: D5.2 (A), D6.1 (K), R7.2
unnamed: D7.2 (A), D8.1 (K), R9.2
unnamed: J3.1, R41.2
unnamed: R3.1, U1.21 (RSET)
unnamed: R3.2, R36.2
unnamed: R7.1, U1.12 (L2)
unnamed: R9.1, U1.11 (L1)
unnamed: R11.1, TH1.1, U1.10 (NTC)
unnamed: R12.1, R13.2, U3.3 (VINA+)
unnamed: R12.2, R17.1, U3.10 (VINC+)
unnamed: R14.2, R15.1, U2.10 (VINC+)
unnamed: R15.2, R16.1, U2.3 (VINA+)
unnamed: R20.1, U3.1 (VOUTA)
unnamed: R21.1, U2.1 (VOUTA)
unnamed: R22.1, U3.6 (VINB-), U3.7 (VOUTB)
unnamed: R23.1, U2.6 (VINB-), U2.7 (VOUTB)
unnamed: R26.2, R27.1, U6.3 (VINA+)
unnamed: R27.2, R28.1, U6.10 (VINC+)
unnamed: R29.2, R30.1, U7.10 (VINC+)
unnamed: R30.2, R31.1, U7.3 (VINA+)
unnamed: R34.1, U6.1 (VOUTA)
unnamed: R35.1, U7.1 (VOUTA)
unnamed: R37.1, U6.6 (VINB-), U6.7 (VOUTB)
unnamed: R38.1, U7.6 (VINB-), U7.7 (VOUTB)
unnamed: S1.2, U1.37 (VOUT1)

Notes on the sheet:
NO2: -25mV
O3: -25mV
See IP5328 Datasheet Pg. 23: http://www.sztuofeng.com/upload/1586854246.pdf
USB-C Port
4.2V Battery => N.C. in place of R14
System Temp Monitor Thermistor
Power System
CO: 3mV
Power Test/Solder Point
SO2: +200mV

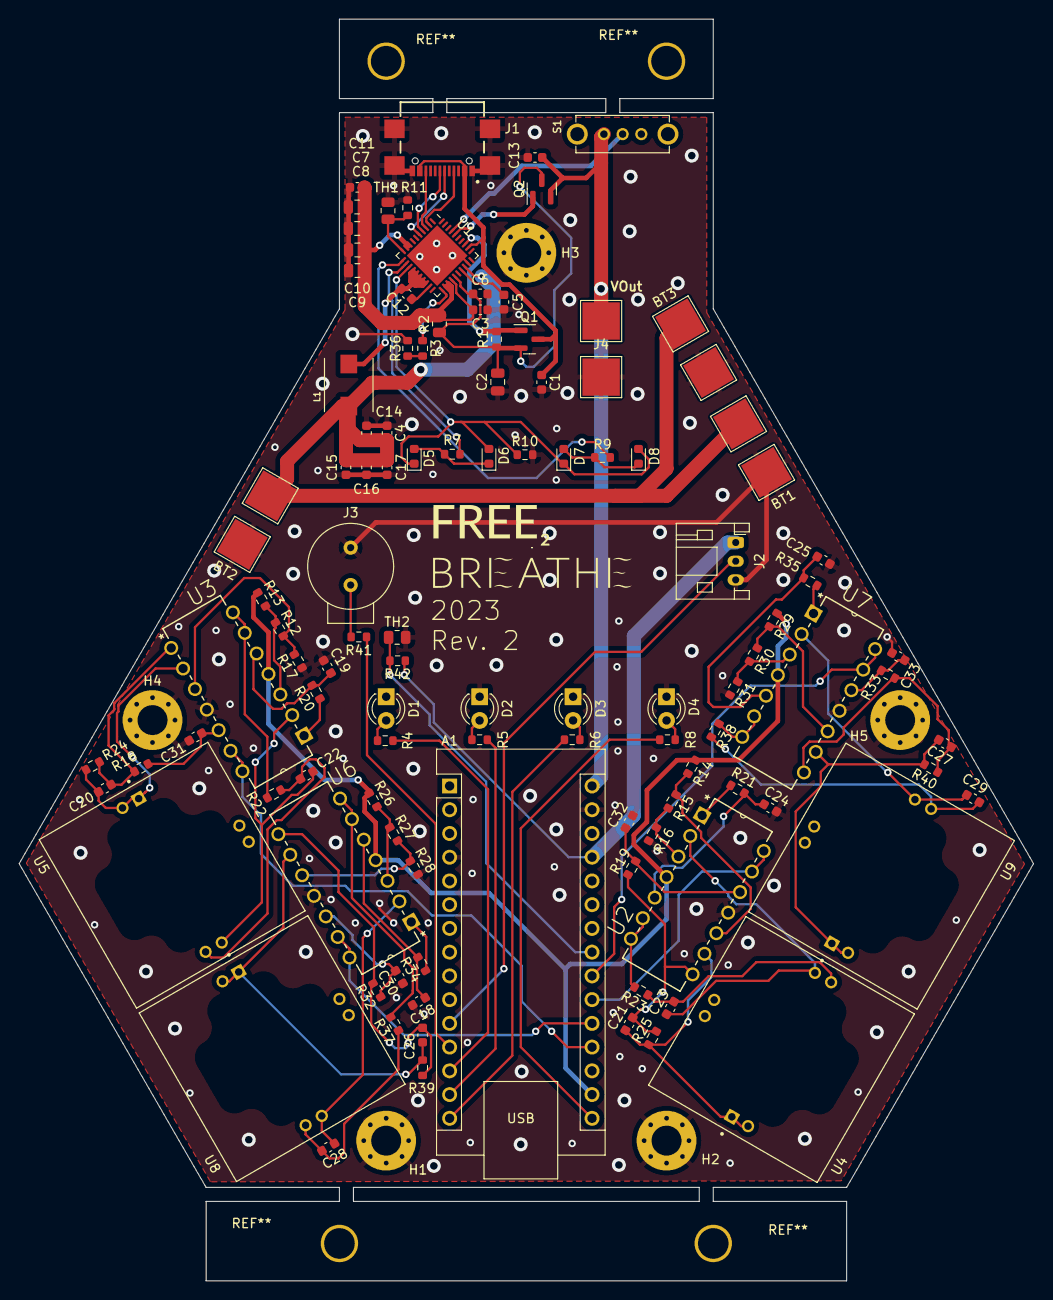
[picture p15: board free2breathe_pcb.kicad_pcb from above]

Board: 2 copper layers, 108.5 x 135.0 mm, 111 parts (0 on the bottom side), 82 nets.

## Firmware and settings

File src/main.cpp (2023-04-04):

#include <Arduino.h>
#include <FastLED.h>

#include "leds/LEDController.h"
#include "ulp/ULP.h"

/***************************************
 * Pin Assignments
 ***************************************/

#define CO_READ_PIN A0
#define SO2_READ_PIN A1
#define O3_READ_PIN A2
#define NO2_READ_PIN A3
#define THERMISTOR_READ_PIN A4

#define CO_STATUS_LED 13
#define SO2_STATUS_LED 12
#define O3_STATUS_LED 11
#define NO2_STATUS_LED 10

#define LED_DATA_PIN 8

#define ALARM_PIN 9

/***************************************
 * Sensors
 ***************************************/

const int sensorReadTime = 2;  // seconds to read gas sensor

// Sensitivities (as shown on sensor barcodes)
// CO: 4.47 nA / ppm
// SO2: 39.23 nA / ppm
// O3: -60 nA +- 10 / ppm
// NO2: -30 nA +- 10 / ppm
const float coSensitivityFactor = 4.47;
const float so2SensitivityFactor = 39.23;
const float o3SensitivityFactor = -60;
const float no2SensitivityFactor = -30;

const float coWorryConcentration = 9;     // ppm
const float coDangerConcentration = 200;  // ppm
const float so2WorryConcentration = 2;    // ppm
const float so2DangerConcentration = 5;   // ppm
const float o3WorryConcentration = 0.1;   // ppm
const float o3DangerConcentration = 0.3;  // ppm
const float no2WorryConcentration = 0.2;  // ppm
const float no2DangerConcentration = 1;   // ppm

bool coPresent = false;
bool so2Present = false;
bool o3Present = false;
bool no2Present = false;

CO COsensor(CO_READ_PIN, THERMISTOR_READ_PIN, coSensitivityFactor);
SO2 SO2sensor(SO2_READ_PIN, THERMISTOR_READ_PIN, so2SensitivityFactor);
O3 O3sensor(O3_READ_PIN, THERMISTOR_READ_PIN, o3SensitivityFactor);
NO2 NO2sensor(NO2_READ_PIN, THERMISTOR_READ_PIN, no2SensitivityFactor);

/***************************************
 * LEDs
 ***************************************/

#define NUM_LEDS 25
#define COLOR_ORDER GRB
CRGB leds[NUM_LEDS];

f2b::LEDController LEDController = f2b::LEDController(leds, NUM_LEDS);

/***************************************
 * Thermistor
 ***************************************/
const unsigned long thermistorNominalRes = 100000;
const unsigned long thermistorSeriesResistor = 100000;
const unsigned thermistorTempNominal = 25;
const unsigned thermistorNumSamples = 50;
const unsigned thermistorBetaCoefficient = 3760;

unsigned i;
float thAverage;
long int thSampleSum;
float temp = 20.0;

/***************************************
 * Timing
 ***************************************/
double runTime = 0.0;
unsigned long sensorPreviousMillis = 0;
unsigned sensorPollPeriod = 20000;
unsigned long tempPreviousMillis = 0;
unsigned tempPeriod = 50;
unsigned long buzzerPreviousMillis = 0;
unsigned buzzerPeriod = 250;
bool alarm = false;
bool buzzerOn = false;

void setup() {
  pinMode(CO_READ_PIN, INPUT);
  pinMode(SO2_READ_PIN, INPUT);
  pinMode(O3_READ_PIN, INPUT);
  pinMode(NO2_READ_PIN, INPUT);
  pinMode(THERMISTOR_READ_PIN, INPUT);

  pinMode(CO_STATUS_LED, OUTPUT);
  pinMode(SO2_STATUS_LED, OUTPUT);
  pinMode(O3_STATUS_LED, OUTPUT);
  pinMode(NO2_STATUS_LED, OUTPUT);

  pinMode(LED_DATA_PIN, OUTPUT);
  pinMode(ALARM_PIN, OUTPUT);

  digitalWrite(CO_STATUS_LED, LOW);
  digitalWrite(SO2_STATUS_LED, LOW);
  digitalWrite(O3_STATUS_LED, LOW);
  digitalWrite(NO2_STATUS_LED, LOW);

  FastLED.addLeds<WS2812B, LED_DATA_PIN, COLOR_ORDER>(leds, NUM_LEDS)
      .setCorrection(TypicalLEDStrip);
  FastLED.setBrightness(50);
  LEDController.currentLEDState = f2b::LEDState::OFF;
  LEDController.UpdateLEDs();

  // bitmasking to set buzzer PWM frequency
  TCCR2B = ((TCCR2B & B11111000) | B00000011);

  // update if micro or power supply changes
  COsensor.pVcc = SO2sensor.pVcc = O3sensor.pVcc = NO2sensor.pVcc = 4.993;
  COsensor.pVsup = SO2sensor.pVsup = O3sensor.pVsup = NO2sensor.pVsup = 3.293;

  // CO
  long int CO_R2 = 1999;  // spec 2k
  float CO_bias = 3.0;
  COsensor.setVref(CO_bias, CO_R2);
  COsensor.pGain = 99900;  // resistor R6, spec 100k

  // SO2
  long int SO2_R2 = 134100;  // spec 143k
  float SO2_bias = 217.0;
  SO2sensor.setVref(SO2_bias, SO2_R2);
  SO2sensor.pGain = 99600;  // spec 100k

  // O3
  long int O3_R2 = 16000;  // spec 16.2k
  float O3_bias = -25;
  O3sensor.setVref(O3_bias, O3_R2);
  O3sensor.pGain = 498000;  // spec 499k

  // NO2
  long int NO2_R2 = 16070;  // spec 16.2k
  float NO2_bias = -25;
  NO2sensor.setVref(NO2_bias, NO2_R2);
  NO2sensor.pGain = 497000;  // spec 499k

  Serial.begin(9600);

  // if V_ref is known replace the following code...

  // Serial.println("Remove Sensor.");
  // if (SO2sensor.OCzero(n)) {
  //   Serial.print("Vref new = ");
  //   Serial.println(SO2sensor.pVref_set);
  // } else {
  //   Serial.println("Recheck Settings, Zero out of range");
  //   while (1) {
  //     Serial.println(analogRead(SO2_READ_PIN));
  //     delay(1000);
  //   }
  // }
  // Serial.println("Finished Setting Up, Replace Sensor Now.\n");

  //...with the measured value of new Vref
  COsensor.pVref_set = 1638.31;
  SO2sensor.pVref_set = 1525.92;
  O3sensor.pVref_set = 1657.67;
  NO2sensor.pVref_set = 1657.12;

  Serial.println("\nSetting Up.");

  Serial.print("  Vsup for all sensors = ");
  Serial.println(COsensor.pVsup);
  Serial.print("  Vcc for all sensors = ");
  Serial.println(COsensor.pVcc);

  Serial.println("\nSystem starting up, please wait for stabilization.");
  Serial.println("\nData Log:");
  Serial.println("s, temp, CO PPM, SO2 PPM, O3 PPM, NO2 PPM");

  sensorPreviousMillis = millis();
  tempPreviousMillis = millis();

  // system startup delay
  for (unsigned i = 0; i <= 25; i++) {
    LEDController.currentLEDState = f2b::LEDState::BLUE;
    LEDController.SetNumLEDs(i);
    LEDController.UpdateLEDs();
    // TODO: update for desired startup time
    delay(50);
  }
}

void loop() {
  runTime = millis() / 1000.0;

  // update temperature reading
  if (millis() - tempPreviousMillis > tempPeriod) {
    thSampleSum += analogRead(THERMISTOR_READ_PIN);
    i++;

    if (i >= thermistorNumSamples) {
      thAverage = thSampleSum / i;

      // convert to resistance
      thAverage = 1023 / thAverage - 1;
      thAverage = thermistorSeriesResistor / thAverage;

      // convert resistance to temperature - see
      // https://learn.adafruit.com/thermistor/using-a-thermistor
      float steinhart;
      steinhart = thAverage / thermistorNominalRes;         // (R/Ro)
      steinhart = log(steinhart);                           // ln(R/Ro)
      steinhart /= thermistorBetaCoefficient;               // 1/B * ln(R/Ro)
      steinhart += 1.0 / (thermistorTempNominal + 273.15);  // + (1/To)
      steinhart = 1.0 / steinhart;                          // Invert
      steinhart -= 273.15;  // convert absolute temp to C

      temp = steinhart;

      thSampleSum = 0;
      thAverage = 0;
      i = 0;
    }
    tempPreviousMillis = millis();
  }

  // update sensor readings
  if (millis() - sensorPreviousMillis > (sensorPollPeriod)) {
    sensorPreviousMillis = millis();

    // turn off lights and alarm to reduce noise while reading
    LEDController.currentLEDState = f2b::LEDState::OFF;
    LEDController.UpdateLEDs();
    digitalWrite(CO_STATUS_LED, LOW);
    digitalWrite(SO2_STATUS_LED, LOW);
    digitalWrite(O3_STATUS_LED, LOW);
    digitalWrite(NO2_STATUS_LED, LOW);
    analogWrite(ALARM_PIN, 0);
    delay(1000);

    COsensor.getIgas(sensorReadTime);
    COsensor.setTemp(temp);
    COsensor.getConc(temp);

    SO2sensor.getIgas(sensorReadTime);
    SO2sensor.setTemp(temp);
    SO2sensor.getConc(temp);

    O3sensor.getIgas(sensorReadTime);
    O3sensor.setTemp(temp);
    O3sensor.getConc(temp);

    NO2sensor.getIgas(sensorReadTime);
    NO2sensor.setTemp(temp);
    NO2sensor.getConc(temp);

    // scale reading based on test data
    float COppm = COsensor.convertX('B') / 1.5;
    float SO2ppm = SO2sensor.convertX('B') / 1.5;
    float O3ppm = O3sensor.convertX('B') / 1.5;
    float NO2ppm = NO2sensor.convertX('B') / 1.5;

    alarm = false;
    if (COppm >= coDangerConcentration || SO2ppm >= so2DangerConcentration ||
        O3ppm >= o3DangerConcentration || NO2ppm >= no2DangerConcentration) {
      alarm = true;
    }

    coPresent = false;
    so2Present = false;
    o3Present = false;
    no2Present = false;

    if (COppm > coWorryConcentration) {
      coPresent = true;
    }
    if (SO2ppm > so2WorryConcentration) {
      so2Present = true;
    }
    if (O3ppm > o3WorryConcentration) {
      o3Present = true;
    }
    if (NO2ppm > no2WorryConcentration) {
      no2Present = true;
    }

    if (alarm) {
      LEDController.currentLEDState = f2b::LEDState::RED;
    } else if (coPresent || so2Present || o3Present || no2Present) {
      LEDController.currentLEDState = f2b::LEDState::YELLOW;
    } else {
      LEDController.currentLEDState = f2b::LEDState::GREEN;
    }

    digitalWrite(CO_STATUS_LED, coPresent);
    digitalWrite(SO2_STATUS_LED, so2Present);
    digitalWrite(O3_STATUS_LED, o3Present);
    digitalWrite(NO2_STATUS_LED, no2Present);

    LEDController.UpdateLEDs();

    Serial.print(runTime);
    Serial.print(", ");
    Serial.print(temp);
    Serial.print(", ");
    Serial.print(COppm);
    Serial.print(", ");
    Serial.print(SO2ppm);
    Serial.print(", ");
    Serial.print(O3ppm);
    Serial.print(", ");
    Serial.println(NO2ppm);
  }

  // sound alarm if appropriate
  if (alarm) {
    if (millis() - buzzerPreviousMillis >= buzzerPeriod) {
      buzzerOn = !buzzerOn;
      buzzerPreviousMillis = millis();
    }
    if (buzzerOn) {
      analogWrite(ALARM_PIN, 128);
    } else {
      analogWrite(ALARM_PIN, 0);
    }
  } else {
    analogWrite(ALARM_PIN, 0);
  }
}

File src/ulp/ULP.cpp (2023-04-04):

/*
  ULP.cpp - Library for reading SPEC Sensors ULP.
  Revised by David E. Peaslee, May 22, 2020.
  Created by David E. Peaslee, OCT 27, 2016.
  Released into the public domain.
*/

#include "ULP.h"

#include "Arduino.h"

ULP::ULP(int a, int b, float c) : pCPin(a), pTPin(b), pSf(c) {
  pTzero = 25.0;
  pIzero = 0.0;

  // Temperature Sensor Settings
  pHtemp = 40.0;
  pLtemp = 20.0;                          // temps for cal of temp sensor
  pTb = 18.0;                             // temperature sensor coef
  pTs = 87.0;                             // temperature sensor coef
  pHvolt = (pHtemp + pTb) * pVsup / pTs;  // volts for cal of temp sensor
  pLvolt = (pLtemp + pTb) * pVsup / pTs;  // volts for cal of temp sensor
}

// float ULP::pVcc = 5.0;
// float ULP::pVsup = 3.3;

void ULP::setTemp(float t) { pT = t; }

float ULP::convertT(char U) {
  if (U == 'F') {
    float TempF = pT * 9 / 5 + 32;
    return TempF;
  } else if (U == 'C') {
    return pT;
  } else
    return 0;
}

float ULP::convertX(char U) {
  if (U == 'B')
    return pX;
  else if (U == 'M')
    return (pX / 1000.0);
  else
    return 0;
}

void ULP::setTSpan(float t, String R) {
  Serial.print("Old temp. span and offset: ");
  Serial.print(pTs);
  Serial.print(", ");
  Serial.println(pTb);
  unsigned long etime, i = 0, n = 10;
  unsigned long anaCounts = 0;
  etime = millis() + n * 1000;
  do {
    anaCounts = anaCounts + analogRead(pTPin);
    delay(1);
    i++;
  } while (millis() < etime);
  float Cnts = float(anaCounts) / float(i);
  float Volts = Cnts * pVcc / 1024;

  if (R == "HIGH") {
    pHtemp = t;
    pHvolt = Volts;
  } else if (R == "LOW") {
    pLtemp = t;
    pLvolt = Volts;
  }
  pTs = pVsup * (pHtemp - pLtemp) / (pHvolt - pLvolt);
  pTb = pLvolt * (pHtemp - pLtemp) / (pHvolt - pLvolt) - pLtemp;
  Serial.print("New temp. span and offset: ");
  Serial.print(pTs);
  Serial.print(", ");
  Serial.println(pTb);
}

void ULP::setVref(int b, long R2) {
  // Calculate Expected Vref
  if (b >= 0)
    pVref = pVsup * float(R2 + 1000000) / float(R2 + 2000000) * 1000.0;
  else
    pVref = pVsup * float(1000000) / float(R2 + 2000000) * 1000.0;
  pVref_set = pVref;
}

bool ULP::OCzero(int n) {
  // Measure real Vref
  unsigned long etime, i = 0;
  unsigned long anaCounts = 0;
  Serial.println("Send any character when sensor is removed.");
  while (Serial.available() <= 0) {
  }
  Serial.println("Zeroing");
  Serial.flush();
  etime = millis() + n * 1000;
  do {
    anaCounts = anaCounts + analogRead(pCPin);
    delay(1);
    i++;
  } while (millis() < etime);
  float Cnts = float(anaCounts) / float(i);
  pVref_set = Cnts * pVcc * 1000.0 / 1024.0;  // in mV
  Serial.print("  pVref: ");
  Serial.println(pVref);
  Serial.print("  pVref_set: ");
  Serial.println(pVref_set);
  Serial.print("  disparity = ");
  Serial.println(pVref - pVref_set);

  if (abs(pVref - pVref_set) > 50)
    return false;
  else
    return true;
}

void ULP::zero() {
  Serial.println("zero()");
  pIzero = pInA;
  pTzero = pT;
}

void ULP::getIgas(int n) {
  // Serial.println("getIgas()");
  unsigned long etime, i = 0;
  unsigned long anaCounts = 0;
  etime = millis() + n * 1000;
  do {
    anaCounts = anaCounts + analogRead(pCPin);
    delay(1);
    i++;
  } while (millis() < etime);
  float Cnts = float(anaCounts) / float(i);

  pVgas = Cnts * pVcc * 1000.0 / 1024.0;  // in mV

  // Serial.print("  mV: ");
  // Serial.println(pVgas);

  pInA = (pVgas - pVref_set) / pGain * 1000.0;  // in nA

  // Serial.print("  nA: ");
  // Serial.println(pInA);
}

void ULP::getConc(float t) {
  // Serial.println("getConc()");
  float nA = pInA - pIzero * expI(t - pTzero);
  float Sens = pSf * (1.0 + pTc * (t - 20.0));
  pX = nA / Sens * 1000.0;  // output in ppb

  // pX = pInA / pSf * 1000.0;
  // Serial.print("  PPB: ");
  // Serial.println(pX);
}

float ULP::expI(float T) { return exp(T / pn); }

void ULP::setXSpan() {
  Serial.setTimeout(10000);
  float X;
  float nA, Sf;
  Serial.print(
      "When gas concentration steady, enter Concentration in ppm followed by "
      "'cr' = ");
  while (Serial.available() <= 0) {
  }
  X = Serial.parseFloat();
  Serial.println(X);
  getIgas(10);

  Sf = pInA / X;
  if (abs(Sf - pSf) * 2 / (Sf + pSf) < .1) {
    pSf = Sf;
  } else {
    Serial.println("Error Setting Span");
  }
}

EtOH::EtOH(int a, int b, float c) : ULP(a, b, c = 14.0) {
  setVref(+100, 69800);
  pGain = 249.0;
  pn = 1;
  pTc = 0.01;
}

H2S::H2S(int a, int b, float c) : ULP(a, b, c = 194.0) {  // works
  setVref(+3, 2000);
  pGain = 49.9;
  pn = -300.0;
  pTc = 0.007;
}

CO::CO(int a, int b, float c) : ULP(a, b, c = 2.44) {
  setVref(+3, 2000);
  pGain = 100.0;
  pn = 13.6;
  pTc = 0.007;
}

IAQ::IAQ(int a, int b, float c) : ULP(a, b, c = 150.0) {
  setVref(+150, 105000);
  pGain = 100.0;
  pn = 1;
  pTc = 0.01;
}

SO2::SO2(int a, int b, float c) : ULP(a, b, c = 14.6) {
  setVref(+200, 143000);
  pGain = 100.0;
  pn = 10.26;
  pTc = -0.026;
}

NO2::NO2(int a, int b, float c) : ULP(a, b, c = -25.0) {
  setVref(-25, 16200);
  pGain = 499.0;
  pn = 109.6;
  pTc = 0.005;
}

RESP::RESP(int a, int b, float c) : ULP(a, b, c = -21.5) {
  setVref(-200, 143000);
  pGain = 499.0;
  pn = 1;
  pTc = 0.00;
}

O3::O3(int a, int b, float c) : ULP(a, b, c = -20.0) {
  setVref(-25, 16200);
  pGain = 499.0;
  pn = 109.6;
  pTc = -0.005;
}

SPEC::SPEC(int a, int b, float c) : ULP(a, b, c = 1.0) {}

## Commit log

2022-10-17 add basic sensor test code, platformio project, component list
2022-10-17 add kicad project, update gitignore to remove kicad temp files
    [free2breathe_pcb.kicad_pcb, free2breathe_pcb.kicad_sch]
2022-11-11 start adding pcb components, update gitignore
    [free2breathe_pcb.kicad_sch]
2022-11-19 add LED controller
2022-11-21 add led pulse effect, verify LED functionality
2022-11-22 fix LED color order, add loading effect
    [main.cpp]
2022-11-22 update README, add USB-C connector to schematic
    [free2breathe_pcb.kicad_sch]
2022-12-02 update CO sensor reading sketch
2022-12-02 incorporate CO sensor code
2023-01-10 add additional components, symbols and footprints
    [110-102.step, free2breathe_pcb.kicad_sch]
2023-01-11 add status LEDs and connectors
    [free2breathe_pcb.kicad_sch]
2023-01-16 added switch to schematic
    [free2breathe_pcb.kicad_sch]
2023-01-17 add sensor biasing, assign footprints
    [AMPLA5030S2R2MT.step, MCP6044-E_P.step, free2breathe_pcb.kicad_sch]
2023-01-18 additional footprints, update todo
    [free2breathe_pcb.kicad_sch]
2023-01-20 Sensor code (#1)
    * add basic code for additional sensors
    * add voltage reader
2023-01-23 completed rev1 board schematic
    [USB4110-GF-A_REVB.step, free2breathe_pcb.kicad_sch]
2023-01-23 begun sorting components on layout
    [free2breathe_pcb.kicad_pcb]
2023-01-23 group sensors with supporting hardware
    [free2breathe_pcb.kicad_pcb, free2breathe_pcb.kicad_sch]
2023-01-23 begin board layout
    [free2breathe_pcb.kicad_pcb]
2023-01-23 rest of components placed in board (very poorly)
    [free2breathe_pcb.kicad_pcb]
2023-01-23 add new PCB shape, move todo out of /src
    [free2breathe_pcb.kicad_pcb]
2023-01-23 initial arrangement for new layout, add mounting holes
    [free2breathe_pcb.kicad_pcb, free2breathe_pcb.kicad_sch]
2023-01-24 further refinement
    [free2breathe_pcb.kicad_pcb, free2breathe_pcb.kicad_sch]
2023-01-24 placed components, changed power LEDs
    [free2breathe_pcb.kicad_pcb, free2breathe_pcb.kicad_sch]
2023-01-24 some routing done around the bottom sensors
    [free2breathe_pcb.kicad_pcb]
2023-01-24 more routing
    [free2breathe_pcb.kicad_pcb, free2breathe_pcb.kicad_sch]
2023-01-24 add 3d models
    [EG1213.step, free2breathe_pcb.kicad_pcb, free2breathe_pcb.kicad_sch]
2023-01-24 update step file to include standard components
    [free2breathe_pcb.kicad_pcb, free2breathe_pcb.kicad_sch]
2023-01-24 update components and todo, swap current-sense resistor to 0805
    [free2breathe_pcb.kicad_pcb, free2breathe_pcb.kicad_sch]
2023-01-25 further routing, ground planes and sticthing vias
    [free2breathe_pcb.kicad_pcb]
2023-01-26 add BOM, update board with component replacements
    [BOM.xlsx, free2breathe_pcb.kicad_pcb, free2breathe_pcb.kicad_sch]
2023-01-27 moved silkscreen
    [free2breathe_pcb.kicad_pcb]
2023-01-27 add fabrication files, update todo
    [free2breathe_pcb-B_Cu.gbl, free2breathe_pcb-B_Mask.gbs, free2breathe_pcb-B_Paste.gbp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]
2023-01-31 update step file, remove non-ready sensor code
2023-02-03 changed schematic to new sensor cirucit
    [free2breathe_pcb.kicad_sch]
2023-02-06 start layout v2
    [free2breathe_pcb.kicad_pcb, free2breathe_pcb.kicad_sch]
2023-02-06 changed LED resistors, placed rev2 components
    [free2breathe_pcb.kicad_pcb, free2breathe_pcb.kicad_sch]
2023-02-07 completed rev2
    [free2breathe_pcb.kicad_pcb]
2023-02-07 checked for drc compliance
    [free2breathe_pcb.kicad_pcb]
2023-02-11 Ulp (#2)
    * add ulp source files
    * update with circuit parameters
    * framework for additional sensors
    * add temperature monitoring
    * add buzzer and led control
    [ULP.cpp, main.cpp]
2023-02-13 update board, todo, components
    [free2breathe_pcb.kicad_pcb, free2breathe_pcb.kicad_sch]
2023-02-14 update for testing, remove old sensor code
2023-02-20 added BOMrev2
    [BOM.xlsx, BOMrev2.csv]
2023-02-24 compile shopping list, update BOM
    [BOMrev2.xlsx]
2023-03-06 add PCB stencil features
    [free2breathe_pcb-B_Cu.gbl, free2breathe_pcb-B_Mask.gbs, free2breathe_pcb-B_Paste.gbp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]
2023-03-06 add stencil jig
    [free2breathe_pcb.kicad_pcb, stencil_jig.SLDPRT]
2023-03-10 update HTML link, lock alignment holes
    [free2breathe_pcb.kicad_pcb]
2023-03-10 actually add updates
    [BOMrev2.xlsx]
2023-03-10 update hole spacing on stencil jig
    [stencil_jig.SLDPRT]
2023-03-10 adjust stencil jig hole depth
    [stencil_jig.SLDPRT]
2023-03-17 update BOM after assembly
    [BOMrev2.xlsx]
2023-03-24 update schematic for proper x-istor placement, software for testing rev. 2
    [free2breathe_pcb.kicad_sch]
2023-04-04 corrected transistor layout
    [free2breathe_pcb.kicad_pcb]
2023-04-04 Code cleanup (#3)
    * clean up main routine, fix webpage resource link
    * add branch updates
    * prettify webpage
    * add reading for all sensors, cleanup and README update
    [ULP.cpp, main.cpp]
